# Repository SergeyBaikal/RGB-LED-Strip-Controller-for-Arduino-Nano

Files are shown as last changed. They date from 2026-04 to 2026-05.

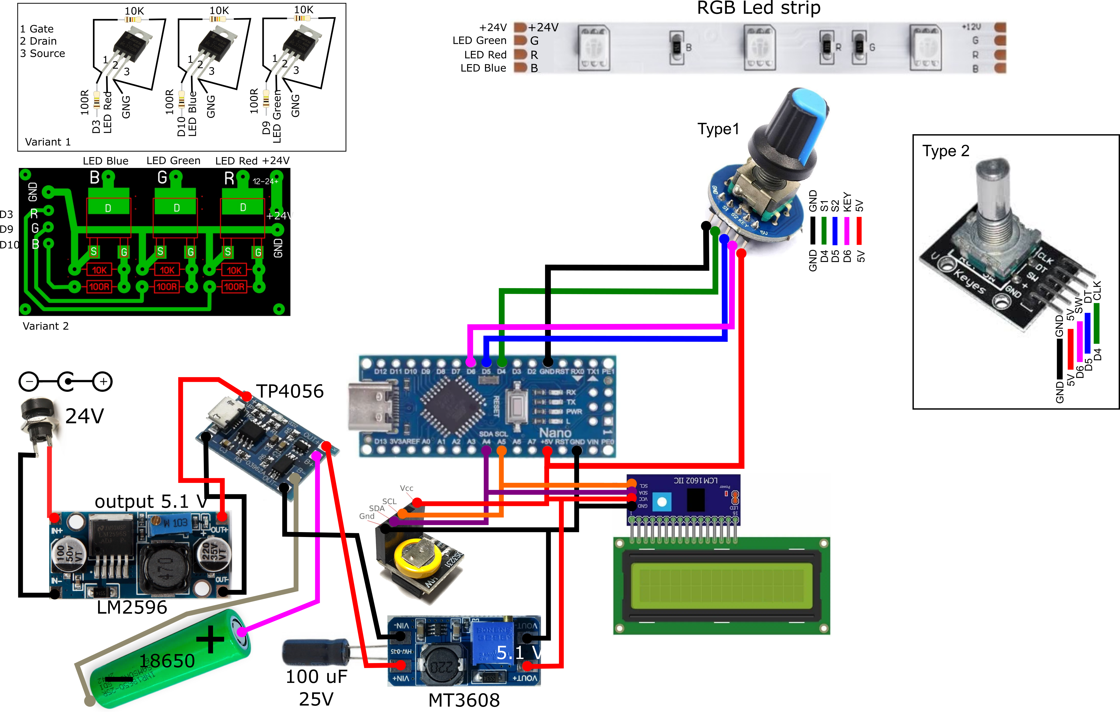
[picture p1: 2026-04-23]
Scheme_with_battery.png

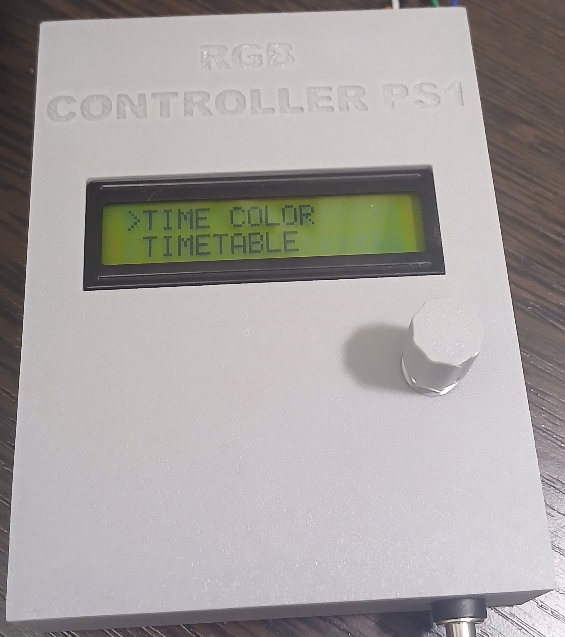
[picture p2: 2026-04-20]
Appearance of the device.jpg

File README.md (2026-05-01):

# RGB-LED-Strip-Controller-for-Arduino-Nano
Проект представляет собой контроллер на базе Arduino Nano для управления светодиодной RGB лентой с общим анодом и напряжением 12–24В. Устройство позволяет вручную настраивать цвета и автоматически включать их по расписанию на каждый день недели.

###  Аппаратные возможности
*   Управление лентой через MOSFET транзисторы (ШИМ).
*   Высокочастотный программный ШИМ для устранения мерцания (по умолчанию 62.5 кГц, можно менять, см. страницу AlexGyver на github GyverPWM и таблицу ниже).
*   Запоминает время после отключения питания благодаря модулю часов реального времени DS3231.
*   Энергонезависимая память: все настройки сохраняются после отключения питания.
*   Версия с аккумулятором позволит продолжить работу режима RUN во время отключения электроэнергии.

---

## Комплектующие и схема подключения

Для сборки понадобятся (см. также схему):

| Компонент | Количество | Примечание |
| :--- | :---: | :--- |
| Arduino Nano | 1 | Протестирована только Nano |
| RTC модуль DS3231 | 1 | Лучше уменьшенную версию с выводами +, D, C и - т.к. компактнее.  |
| LCD Экран 1602 с I2C | 1 | После включения не забудьте подкрутить контрастность. На модуле есть потенциометр для этого. |
| Энкодер с кнопкой | 1 | как на схеме (см. рисунок) |
| Драйвер для ленты | 3 | MOSFET транзисторы (В корпусе TO-220: IRL3705N, IRLZ44N, IRF3205, в корпусе TO-252: IRLR8726 |
| Блок питания 24В | 1 | Мощность рассчитывается под длину ленты |
| RGB Лента 24В | 1 | С общим анодом (+) |
| Понижающий модуль | 1 | LM2596 |

### Распиновка

Подключение компонентов осуществляется согласно следующей таблице:

| Компонент | Вывод компонента | Пин Arduino Nano |
| :--- | :--- | :--- |
| **Энкодер** | S1 | **D4** |
| | S2 | **D5** |
| | KEY | **D6** |
| **RGB Выходы** | Красный канал | **D3** (Timer 2) |
| | Зеленый канал | **D9** (Timer 1) |
| | Синий канал | **D10** (Timer 1) |
| **Display** | SDA | **A4** |
| | SCL | **A5** |
| **DS3231** | D | **A4** |
| | C | **A5** |
| **Питание** | +5V | VCC модулей RTC и LCD |
| | GND | GND модулей и Arduino |

> **Внимание: Питание 24В**
> Лента питается от блока 24В. Arduino Nano питается от 5В (запитать от 24В через понижающий DC-DC преобразователь).

---

## Логика работы 

Управление осуществляется одним **энкодером**:
*   **Вращение:** Навигация по меню / Изменение значений.
*   **Короткое нажатие (Click):** Выбор пункта / Вход в режим редактирования.
*   **Длинное нажатие (Hold):** Назад / Выход из режима редактирования / Сохранение.

### Главное меню
Главное меню состоит из 8 пунктов.

#### 1. ENABLE COLOR
Включение или выключение пользовательских цветов (всего доступно 6 по умолчанию). Активные цвета участвуют в расписании.
В начале скетча можно менять `#define MAX_COLORS 6`, до 20 цветов должно работать без проблем, не тестировал.

#### 2. SETUP COLOR
Настройка значений RGB (0-255) для выбранного активного цвета.
*   Вращением выберите цвет, кликом войдите в настройку.
*   Выберите курсором (`>`) компонент R, G или B и кликните.
*   Вращением измените значение яркости. Нажмите еще раз для фиксации.
*   Во время настройки лента светится текущим цветом.

#### 3. TIME COLOR
Установка временного интервала работы для каждого цвета.
*   `S` (Start) — время включения.
*   `E` (End) — время выключения.
*   Интервалы не должны пересекаться для одного дня. Если задано пересечение, появится предупреждение `Time overlap!`.
* Т.е. вся работа расписана на 24 часа, если нужно чтобы цвет горел через полночь, нужно настроить два Color до 00:00 и соответственно после.
* Например, нужно чтобы цвет горел с 23:00 до 01:00 следующего дня, нужно настроить Color1 start 23:00 end 00:00 и Color2 start 00:00 end 01:00. Естественно следующий день должен быть включен в расписании.
  
Time00

#### 4. TIMETABLE
Настройка дней недели, по которым будет работать автоматический режим.
*   Выберите день (Mon-Sun) и нажмите для переключения `yes` / `no`.
*   Короткое нажатие (Click) переключает состояние дня:
    *   **`yes`** — в этот день расписание работает. Лента будет включаться по заданным интервалам.
    *   **`no`** — в этот день расписание отключено. Лента светиться не будет, на экране в режиме RUN будет надпись **`Today Off Leds`**.

#### 5. CLOCK
Ручная установка времени и даты в модуле DS3231 (Устанавливается атоматически при заливке скетча). Можно использовать при замене батарейки или если по какой то причине время установилось не верно.

#### 6. TEST
Быстрый тест каналов. Поочередно включает Красный, Зеленый и Синий на полную яркость для проверки подключения транзисторов.

#### 7. RUN
**Основной режим работы.**
*   При входе запускается планировщик. На главном экране отображается текущее время, дата и статус ленты (Какой цвет активен и когда закончится / Какой цвет будет следующим).
*   **Короткое нажатие (Click):** Показать текущие значения RGB на 3 секунды.
*   **Длинное нажатие (Hold):** Остановить планировщик и выключить ленту (появится `JOB STOP`).

#### 8. DISPLAY
Управление подсветкой экрана для экономии энергии:
*   `OFF` — отключает подсветку
*   `15MIN` — гаснет через 15 минут бездействия.
*   `1HOUR` — гаснет через 1 час.
*   `ALWAYS` — горит постоянно.

---

## Компиляция и загрузка прошивки

Важно! Отключайте внешнее питание при загрузке скетча (блок питания, если подключен).
### Настройка ШИМ в скетче

* Выбор режима ШИМ:  
`#define PWM_MODE 0`  
   0 - Fast PWM  
   1 - Phase-correct PWM 

* Выбор частоты ШИМ (см. таблицу):  
`#define PWM_PRESCALER 1`   
### ТАБЛИЦА ЧАСТОТ ШИМ ДЛЯ ARDUINO NANO
| Режим | Таймер 1 (пины 9 и 10) 8 bit | Таймер 1 (пины 9 и 10) 8 bit | Таймер 2 (пины 3 и 11) 8 bit | Таймер 2 (пины 3 и 11) 8 bit |
|:---:|:---:|:---:|:---:|:---:|
|  | *Phase-correct PWM* | *Fast PWM* | *Phase-correct PWM* | *Fast PWM* |
| **1** | 31.4 кГц | 62.5 кГц | 31.4 кГц | 62.5 кГц |
| **2** | 4 кГц | 7.8 кГц | 4 кГц | 8 кГц |
| **3** | 490 Гц | 976 Гц | 980 Гц | 2 кГц |
 
### Зависимости (Библиотеки)
Перед компиляцией убедитесь, что в Arduino IDE установлены следующие библиотеки (Менеджер библиотек: *Скетч -> Подключить библиотеку -> Управлять библиотеками*):

1.  **LiquidCrystal_I2C v.2.0.0** (by Frank de Brabander)
2.  **EncButton v.3.7.4** (by AlexGyver)
3.  **GyverDS3231 v.1.2.0** (by AlexGyver)
4.  **GyverPWM v.1.6.1** (by AlexGyver)

### Настройки платы
1.  Выберите плату: `Arduino Nano`.
2.  Процессор: `ATmega328P (Old Bootloader)` (если с новым не загружается).
3.  Порт: Выберите COM-порт вашей платы.
4.  Скопируйте код в окно Arduino IDE или откройте файл с расширением .ino.
Примечание: файл ino должен лежать в одноименной папке, например RGB.ino должен лежать в папке RGB.
Примечание: чтобы инвертировать поворот энкодера, нужно просто сменить знак: `int8_t change = -enc.dir();` // Можно убрать `-`, чтобы инвертировать, по умолчанию `int8_t change = enc.dir();`
5.  Нажмите кнопку "Загрузить" (стрелка вправо). Дождитесь окончания загрузки.
6.  Отключить от USB (!) если хотите сразу подключить к блоку питания, но можно не подключать блок питания, а потестировать работоспособность энкодера и управление через меню.

### Первый запуск
1.  После включения на экране появится заставка с версией прошивки и `RTC OK` или `RTC ERROR`.
2.  Если `RTC ERROR`, проверьте подключение модуля DS3231 или перезалейте скетч.
3.  Зайдите в меню **CLOCK** и установите правильное время (если оно по какой то причине отличается).

---

## Структура хранения в EEPROM

Все настройки (цвета, дни недели, таймаут экрана) хранятся в энергонезависимой памяти. При изменении любого параметра в меню автоматически происходит сохранение через 1-2 секунды.

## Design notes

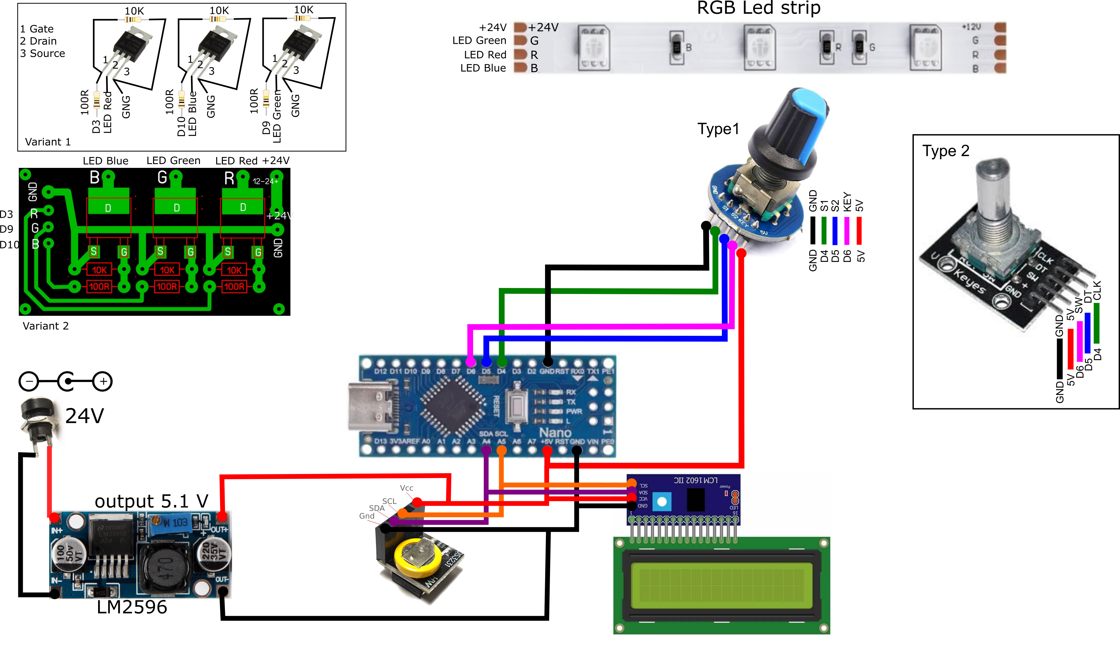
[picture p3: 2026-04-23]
Scheme_without_battery.png

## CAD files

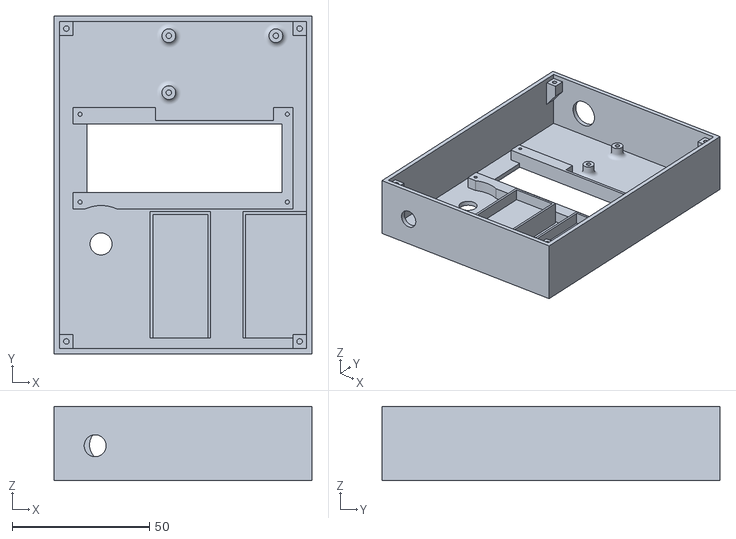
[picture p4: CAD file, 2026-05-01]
RGB_box.stl
94.0 x 123.0 x 27.0

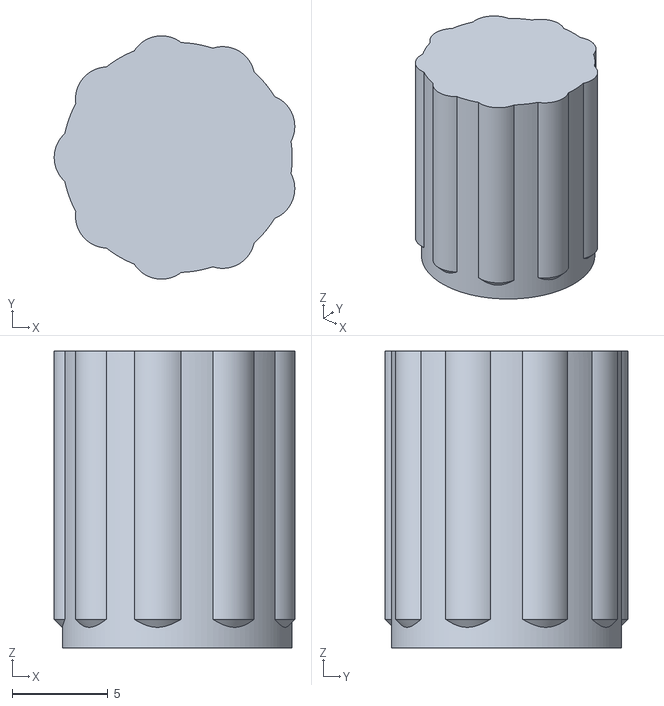
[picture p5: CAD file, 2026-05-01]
knob.stl
12.6 x 12.7 x 15.5

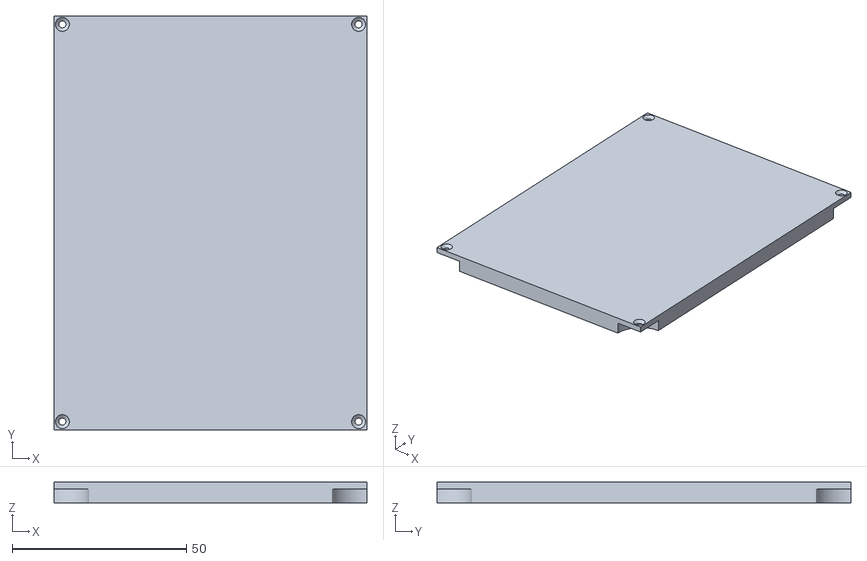
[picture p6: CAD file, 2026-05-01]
Bottom.stl
89.8 x 118.8 x 6.00

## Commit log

2026-04-20 Appearance of the device
2026-05-01 Box parts
    [Bottom.stl, RGB_box.stl, knob.stl]
